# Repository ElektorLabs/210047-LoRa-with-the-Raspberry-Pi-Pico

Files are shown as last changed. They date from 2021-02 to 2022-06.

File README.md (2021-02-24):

# 210047 LoRa with the Raspberry Pi Pico

## Software

 MicroPython scripts for the Raspberry Pi Pico, to get LoRaWAN
 uses a RFM95 module 

## Hardware 
 First version of a Raspberry Pi Pico project adding a RFM95 , DS18B20 and a recharable power supply to it.
 Done with KiCad and work in progress, so use at your own risk.

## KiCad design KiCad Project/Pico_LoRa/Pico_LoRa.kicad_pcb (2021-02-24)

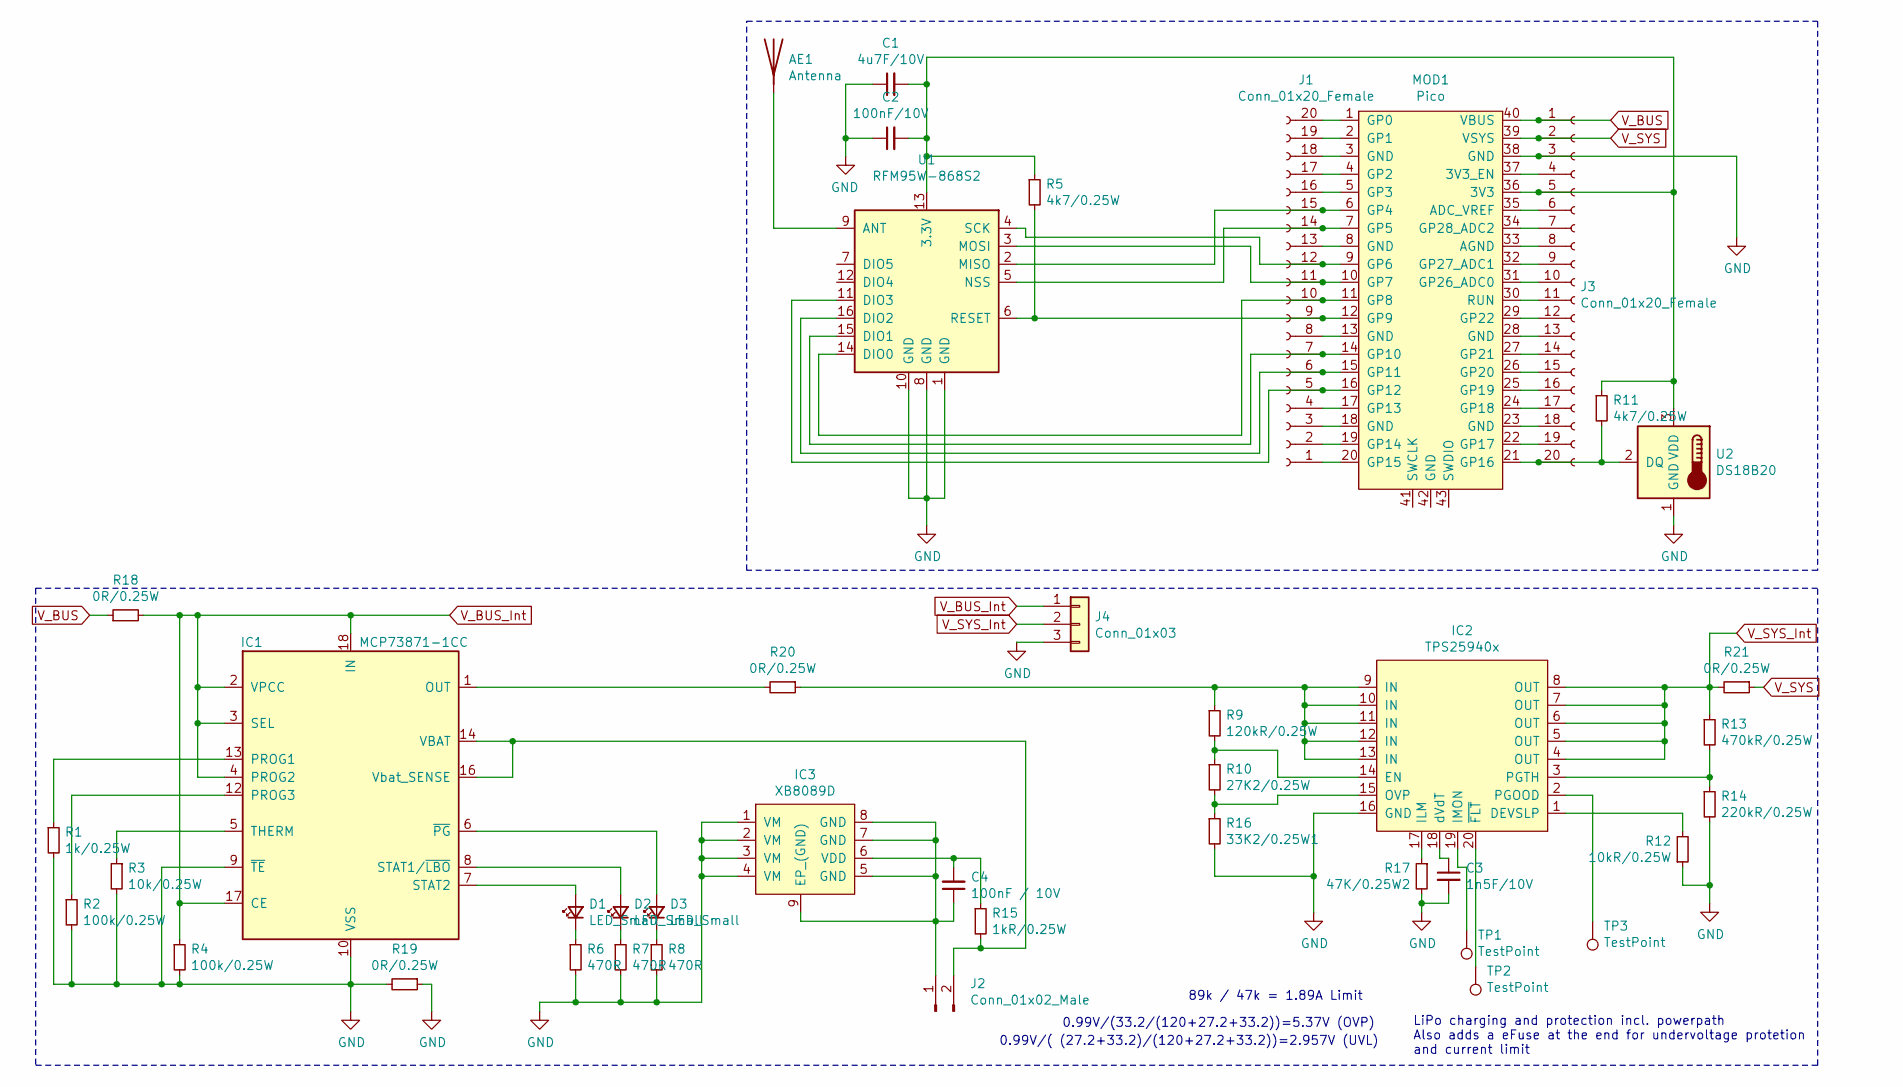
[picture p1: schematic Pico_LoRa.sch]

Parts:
AE1: Antenna; PinHeader_1x01_P2.54mm_Vertical
C1: 4u7F/10V; C_0805_2012Metric_Pad1.18x1.45mm_HandSolder
C2: 100nF/10V; C_0805_2012Metric_Pad1.18x1.45mm_HandSolder
C3: 1n5F/10V; C_0805_2012Metric_Pad1.18x1.45mm_HandSolder
C4: 100nF / 10V; C_0805_2012Metric_Pad1.18x1.45mm_HandSolder
D1, D2, D3: LED_Small; LED_0805_2012Metric_Pad1.15x1.40mm_HandSolder
IC1: MCP73871-1CC; QFN-20-1EP_4x4mm_P0.5mm_EP2.5x2.5mm
IC2: TPS25940x; TI_WQFN_20_EP
IC3: XB8089D
J1, J3: Conn_01x20_Female; PinSocket_1x20_P2.54mm_Vertical
J2: Conn_01x02_Male; PinSocket_1x02_P2.54mm_Vertical
J4: Conn_01x03; PinHeader_1x03_P2.54mm_Vertical
MOD1: Pico; RPi_Pico_SMD_TH
R1: 1k/0.25W; R_0805_2012Metric_Pad1.20x1.40mm_HandSolder
R2, R4: 100k/0.25W; R_0805_2012Metric_Pad1.20x1.40mm_HandSolder
R3: 10k/0.25W; R_0805_2012Metric_Pad1.20x1.40mm_HandSolder
R5, R11: 4k7/0.25W; R_0805_2012Metric_Pad1.20x1.40mm_HandSolder
R6, R7, R8: 470R; R_0805_2012Metric_Pad1.20x1.40mm_HandSolder
R9: 120kR/0.25W; R_0805_2012Metric_Pad1.20x1.40mm_HandSolder
R10: 27K2/0.25W; R_0805_2012Metric_Pad1.20x1.40mm_HandSolder
R12: 10kR/0.25W; R_0805_2012Metric_Pad1.20x1.40mm_HandSolder
R13: 470kR/0.25W; R_0805_2012Metric_Pad1.20x1.40mm_HandSolder
R14: 220kR/0.25W; R_0805_2012Metric_Pad1.20x1.40mm_HandSolder
R15: 1kR/0.25W; R_0805_2012Metric_Pad1.20x1.40mm_HandSolder
R16: 33K2/0.25W1; R_0805_2012Metric_Pad1.20x1.40mm_HandSolder
R17: 47K/0.25W2; R_0805_2012Metric_Pad1.20x1.40mm_HandSolder
R18, R19, R20, R21: 0R/0.25W; R_0805_2012Metric_Pad1.20x1.40mm_HandSolder
TP1, TP2, TP3: TestPoint; TestPoint_Pad_D1.0mm
U1: RFM95W-868S2; HOPERF_RFM9XW_SMD
U2: DS18B20; TO-92_Inline

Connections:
GND: C1.1, C2.1, C3.2, IC1.9 (~TE), IC1.10 (VSS), IC1.11 (VSS), IC1.21 (VSS), IC2.16 (GND), IC3.1 (VM), IC3.2 (VM), IC3.3 (VM), IC3.4 (VM), J3.3, J4.3, MOD1.38 (GND), R1.2, R2.2, R3.2, R4.2, R6.2, R7.2, R8.2, R12.1, R14.2, R16.2, R17.2, R19.1, R19.2, U1.1 (GND), U1.8 (GND), U1.10 (GND), U2.1 (GND)
unnamed: AE1.1, U1.9 (ANT)
unnamed: C1.2, C2.2, J3.5, MOD1.36 (3V3), R5.1, R11.1, U1.13 (3.3V), U2.3 (VDD)
unnamed: C3.1, IC2.18 (dVdT)
unnamed: C4.1, IC3.5 (GND), IC3.7 (GND), IC3.8 (GND), IC3.9 (EP_(GND)), J2.1
unnamed: C4.2, IC3.6 (VDD), R15.1
unnamed: D1.1 (K), R6.1
unnamed: D1.2 (A), IC1.7 (STAT2)
unnamed: D2.1 (K), R7.1
unnamed: D2.2 (A), IC1.8 (STAT1/~LBO~)
unnamed: D3.1 (K), R8.1
unnamed: D3.2 (A), IC1.6 (~PG~)
unnamed: IC1.1 (OUT), IC1.20 (OUT), R20.2
unnamed: IC1.5 (THERM), R3.1
unnamed: IC1.12 (PROG3), R2.1
unnamed: IC1.13 (PROG1), R1.1
unnamed: IC1.14 (VBAT), IC1.15 (VBAT), IC1.16 (Vbat_SENSE), J2.2, R15.2
unnamed: IC2.1 (DEVSLP), R12.2
unnamed: IC2.2 (PGOOD), TP3.1
unnamed: IC2.3 (PGTH), R13.2, R14.1
unnamed: IC2.9 (IN), IC2.10 (IN), IC2.11 (IN), IC2.12 (IN), IC2.13 (IN), R9.1, R20.1
unnamed: IC2.14 (EN), R9.2, R10.1
unnamed: IC2.15 (OVP), R10.2, R16.1
unnamed: IC2.17 (ILM), R17.1
unnamed: IC2.19 (IMON), TP1.1
unnamed: IC2.20 (~FLT), TP2.1
unnamed: J1.1, MOD1.20 (GP15)
unnamed: J1.2, MOD1.19 (GP14)
unnamed: J1.3, MOD1.18 (GND)
unnamed: J1.4, MOD1.17 (GP13)
unnamed: J1.5, MOD1.16 (GP12), U1.11 (DIO3)
unnamed: J1.6, MOD1.15 (GP11), U1.16 (DIO2)
unnamed: J1.7, MOD1.14 (GP10), U1.15 (DIO1)
unnamed: J1.8, MOD1.13 (GND)
unnamed: J1.9, MOD1.12 (GP9), R5.2, U1.6 (RESET)
unnamed: J1.10, MOD1.11 (GP8), U1.14 (DIO0)
unnamed: J1.11, MOD1.10 (GP7), U1.3 (MOSI)
unnamed: J1.12, MOD1.9 (GP6), U1.4 (SCK)
unnamed: J1.13, MOD1.8 (GND)
unnamed: J1.14, MOD1.7 (GP5), U1.5 (NSS)
unnamed: J1.15, MOD1.6 (GP4), U1.2 (MISO)
unnamed: J1.16, MOD1.5 (GP3)
unnamed: J1.17, MOD1.4 (GP2)
unnamed: J1.18, MOD1.3 (GND)
unnamed: J1.19, MOD1.2 (GP1)
unnamed: J1.20, MOD1.1 (GP0)
unnamed: J3.4, MOD1.37 (3V3_EN)
unnamed: J3.6, MOD1.35 (ADC_VREF)
unnamed: J3.7, MOD1.34 (GP28_ADC2)
unnamed: J3.8, MOD1.33 (AGND)
unnamed: J3.9, MOD1.32 (GP27_ADC1)
unnamed: J3.10, MOD1.31 (GP26_ADC0)
unnamed: J3.11, MOD1.30 (RUN)
unnamed: J3.12, MOD1.29 (GP22)
unnamed: J3.13, MOD1.28 (GND)
unnamed: J3.14, MOD1.27 (GP21)
unnamed: J3.15, MOD1.26 (GP20)
unnamed: J3.16, MOD1.25 (GP19)
unnamed: J3.17, MOD1.24 (GP18)
unnamed: J3.18, MOD1.23 (GND)
unnamed: J3.19, MOD1.22 (GP17)
unnamed: J3.20, MOD1.21 (GP16), R11.2, U2.2 (DQ)
V_BUS: J3.1, MOD1.40 (VBUS), R18.1
V_BUS_Int: IC1.2 (VPCC), IC1.3 (SEL), IC1.4 (PROG2), IC1.17 (CE), IC1.18 (IN), IC1.19 (IN), J4.1, R4.1, R18.2
V_SYS: J3.2, MOD1.39 (VSYS), R21.1
V_SYS_Int: IC2.4 (OUT), IC2.5 (OUT), IC2.6 (OUT), IC2.7 (OUT), IC2.8 (OUT), J4.2, R13.1, R21.2

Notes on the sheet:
LiPo charging and protection incl. powerpath Also adds a eFuse at the end for undervoltage protetion and current limit
0.99V/(33.2/(120+27.2+33.2))=5.37V (OVP)
0.99V/( (27.2+33.2)/(120+27.2+33.2))=2.957V (UVL)
89k / 47k = 1.89A Limit

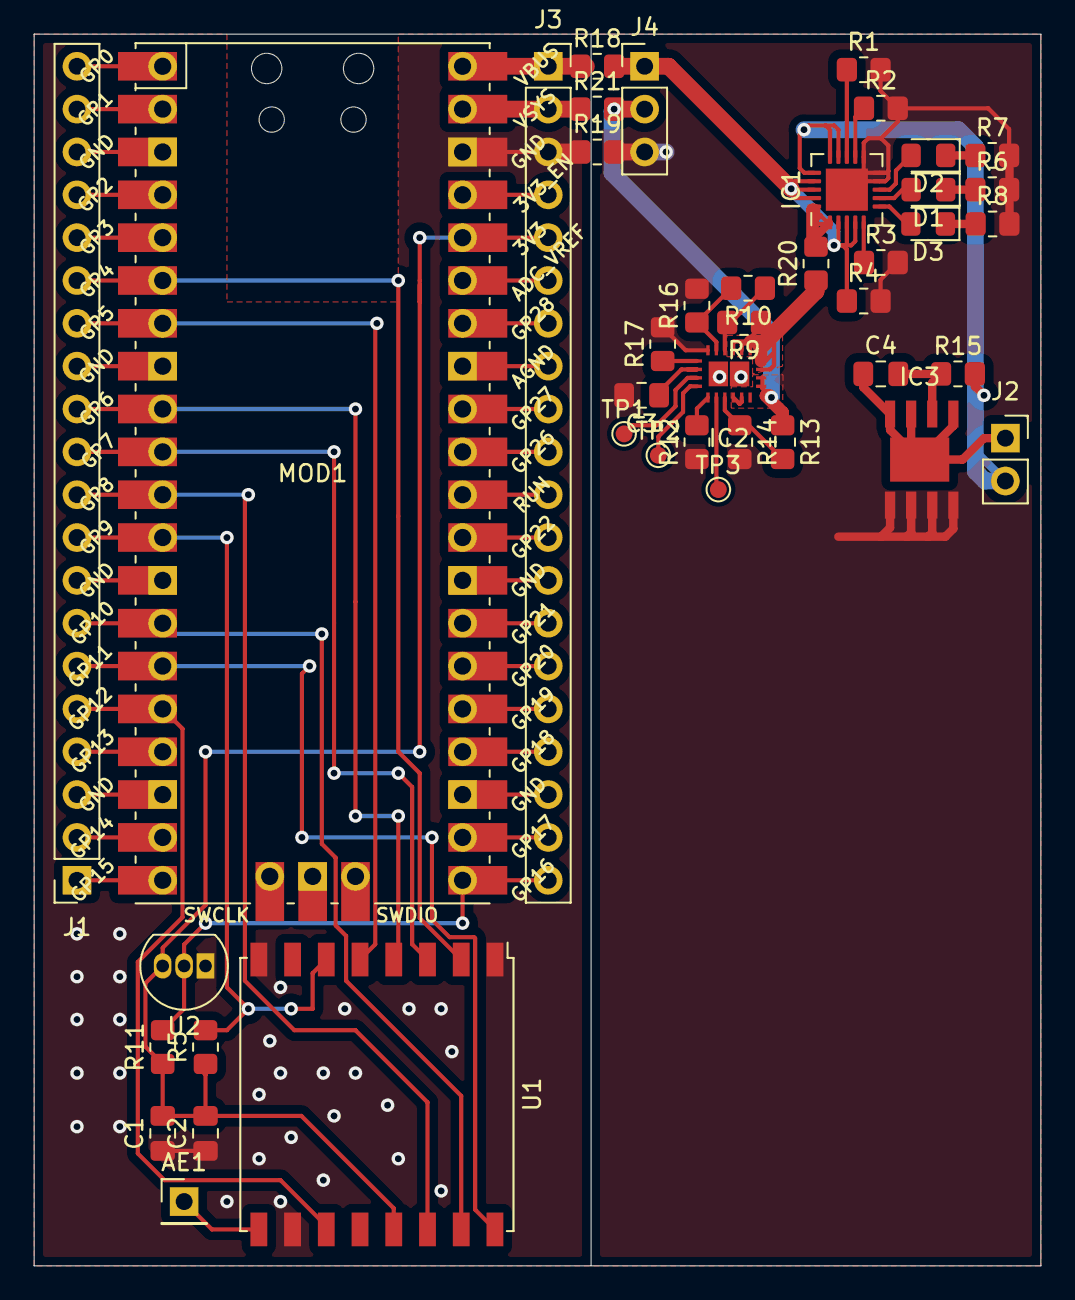
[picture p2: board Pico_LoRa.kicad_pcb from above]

Board: 2 copper layers, 59.7 x 73.0 mm, 42 parts (0 on the bottom side), 66 nets.

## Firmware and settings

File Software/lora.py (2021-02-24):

#import all requiered parts
import machine
import time
import onewire
import ds18x20
import utime
import ubinascii
import os

from micropython import const
from ulora import TTN, uLoRa

#Set the pinout for the RP2040
LORA_SCK = const(6)
LORA_MOSI = const(7)
LORA_MISO = const(4)
LORA_CS = const(5)
LORA_IRQ = const(8)
LORA_RST = const(9)


#LoRa configuration
LORA_DATARATE = "SF9BW125"  # Choose from several available

#Enter the Data for the TTN access here
DEVADDR = bytearray([INSERT DATA HERE])
NWKEY = bytearray([INSERT DATA HERE])
APP = bytearray([INSERT DATA HERE])
#Configure your contry accodtingly for Europe you may use ="EU"
TTN_CONFIG = TTN(DEVADDR, NWKEY, APP, country="EU")
FPORT = 1


#Initialize the RFM95
lora = uLoRa(
    cs=LORA_CS,
    sck=LORA_SCK,
    mosi=LORA_MOSI,
    miso=LORA_MISO,
    irq=LORA_IRQ,
    rst=LORA_RST,
    ttn_config=TTN_CONFIG,
    datarate=LORA_DATARATE,
    fport=FPORT
)

#OneWire setup
dat = machine.Pin(16)

# create the onewire object
ds = ds18x20.DS18X20(onewire.OneWire(dat))

#At this point the hardware is ready to go
# We will now scan for attached 1Wire devices

# scan for devices on the bus
roms = ds.scan()
print('found devices:', roms)
while len(roms ) == 0: 
    print("Sleep for 120 seconds")
    time.sleep(120)
    roms = ds.scan()
    print('found devices:', roms)
    
try:
    f = open('counter.txt','r')
    strval = f.read()
    f.close()
except OSError:  # open failed
   # handle the file open case
    f = open('counter.txt','w')
    f.write('0')
    f.close()
    print("Write new counter.txt with value=0")
    f = open('counter.txt','r')
    strval = f.read()
    f.close()
print(strval)
lora.frame_counter= int(strval)
print("Start with Framecounter="+str(lora.frame_counter))

while True:
    ds.convert_temp()
    time.sleep_ms(750)
    temp = 0
    for rom in roms:
        temp = ds.read_temp(rom)
        print(temp, end=' ')
        print()

    data = b""
    data += "T:"
    data += str(temp)
    print("Sending packet...", lora.frame_counter, ubinascii.hexlify(data))
    lora.send_data(data, len(data), lora.frame_counter)
    print(len(data), "bytes sent!")
    lora.frame_counter += 1
    f = open('counter.txt','w')
    f.write(str(lora.frame_counter))
    f.close()
    print("Sleep for 900 seconds")
    time.sleep(900)

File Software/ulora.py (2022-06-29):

# Copyright 2015, 2016 Ideetron B.V.
#
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
#
# Modified by Brent Rubell for Adafruit Industries.
# Modified by Alan Peaty for MicroPython port.

from micropython import const
from machine import Pin
import machine
import utime
import urandom
import ubinascii
import ulora_encryption

# SX1276 operating mode settings
_MODE_SLEEP = const(0x00)
_MODE_STDBY = const(0x01)
_MODE_FSTX = const(0x02)
_MODE_TX = const(0x03)
_MODE_FSRX = const(0x04)
_MODE_RX = const(0x05)
_MODE_ACCESS_SHARED_REG = const(0x40)
_MODE_LORA = const(0x80)
# SX1276 registers
_REG_FIFO = const(0x00)
_REG_OPERATING_MODE = const(0x01)
_REG_FRF_MSB = const(0x06)
_REG_FRF_MID = const(0x07)
_REG_FRF_LSB = const(0x08)
_REG_PA_CONFIG = const(0x09)
_REG_FIFO_POINTER = const(0x0D)
_REG_RSSI_CONFIG = const(0x0E)
_REG_RSSI_COLLISION = const(0x0F)
_REG_FEI_MSB = const(0x1D)
_REG_FEI_LSB = const(0x1E)
_REG_PREAMBLE_DETECT = const(0x1F)
_REG_PREAMBLE_MSB = const(0x20)
_REG_PREAMBLE_LSB = const(0x21)
_REG_PAYLOAD_LENGTH = const(0x22)
_REG_MODEM_CONFIG = const(0x26)
_REG_TIMER1_COEF = const(0x39)
_REG_NODE_ADDR = const(0x33)
_REG_IMAGE_CAL = const(0x3B)
_REG_TEMP_VALUE = const(0x3C)
_REG_DIO_MAPPING_1 = const(0x40)
_REG_VERSION = const(0x42)
_REG_FIFO_BASE_ADDR = const(0x80)

class TTN:
    """ TTN Class.
    """
    def __init__(self, dev_address, net_key, app_key, country="EU"):
        """ Interface for The Things Network.
        """
        self.dev_addr = dev_address
        self.net_key = net_key
        self.app_key = app_key
        self.region = country

    @property
    def device_address(self):
        """ Returns the TTN Device Address.
        """
        return self.dev_addr
    
    @property
    def network_key(self):
        """ Returns the TTN Network Key.
        """
        return self.net_key

    @property
    def application_key(self):
        """ Returns the TTN Application Key.
        """
        return self.app_key
    
    @property
    def country(self):
        """ Returns the TTN Frequency Country.
        """
        return self.region


class uLoRa:
    """ uLoRa Interface.
    """
    # Fixed data rates for SX1276 LoRa
    _DATA_RATES = {
        "SF7BW125":(0x74, 0x72, 0x04), "SF7BW250":(0x74, 0x82, 0x04),
        "SF8BW125":(0x84, 0x72, 0x04), "SF9BW125":(0x94, 0x72, 0x04),
        "SF10BW125":(0xA4, 0x72, 0x04), "SF11BW125":(0xB4, 0x72, 0x0C),
        "SF12BW125":(0xC4, 0x72, 0x0C)
    }
    # SPI write buffer
    _BUFFER = bytearray(2)

    def __init__(self, cs, sck, mosi, miso, irq, rst, ttn_config, datarate="SF7BW125", fport=1, channel=None):
        """ Interface for a Semtech SX1276 module. Sets module up for sending to
        The Things Network.
        """
        self._irq = machine.Pin(irq, machine.Pin.IN)
        self._cs = machine.Pin(cs, machine.Pin.OUT, value=1)
        self._rst = machine.Pin(rst, machine.Pin.OUT, value=1)
        # Set up SPI device on Mode 0
        self._device = machine.SPI(0,
            baudrate=4000000,
            polarity=0,
            phase=0,
            sck=machine.Pin(sck),
            mosi=machine.Pin(mosi),
            miso=machine.Pin(miso)
        )
        # Verify the version of the SX1276 module
        self._version = self._read_u8(_REG_VERSION)
        if self._version != 18:
            raise TypeError("Can not detect LoRa Module. Please check wiring!")
        # Set Frequency registers
        self._rfm_msb = None
        self._rfm_mid = None
        self._rfm_lsb = None
        # Set datarate registers
        self._sf = None
        self._bw = None
        self._modemcfg = None
        self.set_datarate(datarate)
        self._fport = fport
        # Set regional frequency plan
        if "US" in ttn_config.country:
            from ttn_usa import TTN_FREQS
            self._frequencies = TTN_FREQS
        elif ttn_config.country == "AS":
            from ttn_as import TTN_FREQS
            self._frequencies = TTN_FREQS
        elif ttn_config.country == "AU":
            from ttn_au import TTN_FREQS
            self._frequencies = TTN_FREQS
        elif ttn_config.country == "EU":
            from ttn_eu import TTN_FREQS
            self._frequencies = TTN_FREQS
        else:
            raise TypeError("Country Code Incorrect/Unsupported")
        # Set SX1276 channel number
        self._channel = channel
        self._tx_random = urandom.getrandbits(3)
        if self._channel is not None:
            # Set single channel
            self.set_channel(self._channel)
        # Init FrameCounter
        self.frame_counter = 0
        # Set up SX1276 for LoRa Mode
        for pair in ((_REG_OPERATING_MODE, _MODE_SLEEP), (_REG_OPERATING_MODE, _MODE_LORA),
                     (_REG_PA_CONFIG, 0xFF), (_REG_PREAMBLE_DETECT, 0x25),
                     (_REG_PREAMBLE_MSB, 0x00), (_REG_PREAMBLE_LSB, 0x08),
                     (_REG_MODEM_CONFIG, 0x0C), (_REG_TIMER1_COEF, 0x34),
                     (_REG_NODE_ADDR, 0x27), (_REG_IMAGE_CAL, 0x1D),
                     (_REG_RSSI_CONFIG, 0x80), (_REG_RSSI_COLLISION, 0x00)):
            self._write_u8(pair[0], pair[1])
        # Give the uLoRa object ttn configuration
        self._ttn_config = ttn_config
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

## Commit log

2021-02-24 first commit
    first commit
    [Pico_LoRa.kicad_pcb, Pico_LoRa.sch]
2021-07-21 Added Node Red Flow
    Added Node Red Flow
2022-06-29 Fix for issue #1
    Fixed wrong RST assignment in ulora.py
    [ulora.py]

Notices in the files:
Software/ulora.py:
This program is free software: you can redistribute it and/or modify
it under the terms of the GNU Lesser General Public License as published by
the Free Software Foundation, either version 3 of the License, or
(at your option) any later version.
